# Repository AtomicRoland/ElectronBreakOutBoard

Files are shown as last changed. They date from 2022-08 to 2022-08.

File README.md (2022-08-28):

# ElectronBreakOutBoard
The break out / riser board for the Electron provides a way to check the Electron Plus1 cartridge slot signals during developing and error tracing of (new) boards.

You may choose to mount the 44 pin header strip on either side of the board. Just notice that if you mount it at the keyboard side, then pin 1 is not really pin 1 any more!

To mount the edge connector slot, first bend the pins on both rows slightly until there is a gap of about 1.6 mm. Then push it over the top edge connector (near the header) and solder the pins on both sides. That’s all.

*Please unzip the file myelin-kicad.pretty-master.zip before opening the project in KiCad.*

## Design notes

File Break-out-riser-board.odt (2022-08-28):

# Break out / Riser board for Acorn Electron

The break out / riser board for the Electron provides a way to check the Electron Plus1 cartridge slot signals during developing and error tracing of (new) boards. This board is small and easy to build because it only takes two passive components.

You may choose to mount the 44 pin header strip on either side of the board. Just notice that if you mount it at the keyboard side, then pin 1 is not really pin 1 any more!

To mount the edge connector slot, first bend the pins on both rows slightly until there is a gap of about 1.6 mm. Then push it over the top edge connector (near the header) and solder the pins on both sides. That’s all.

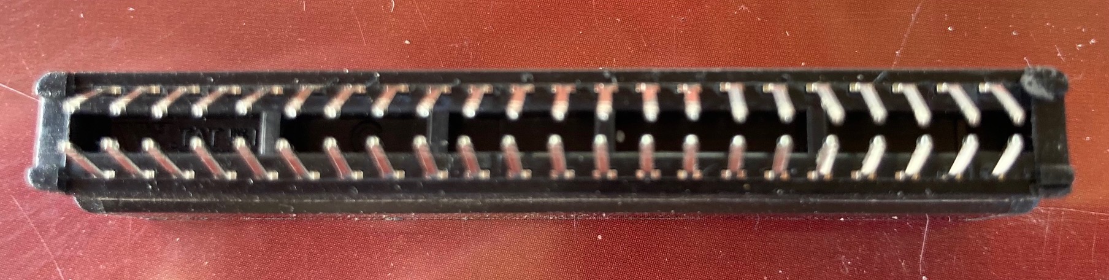
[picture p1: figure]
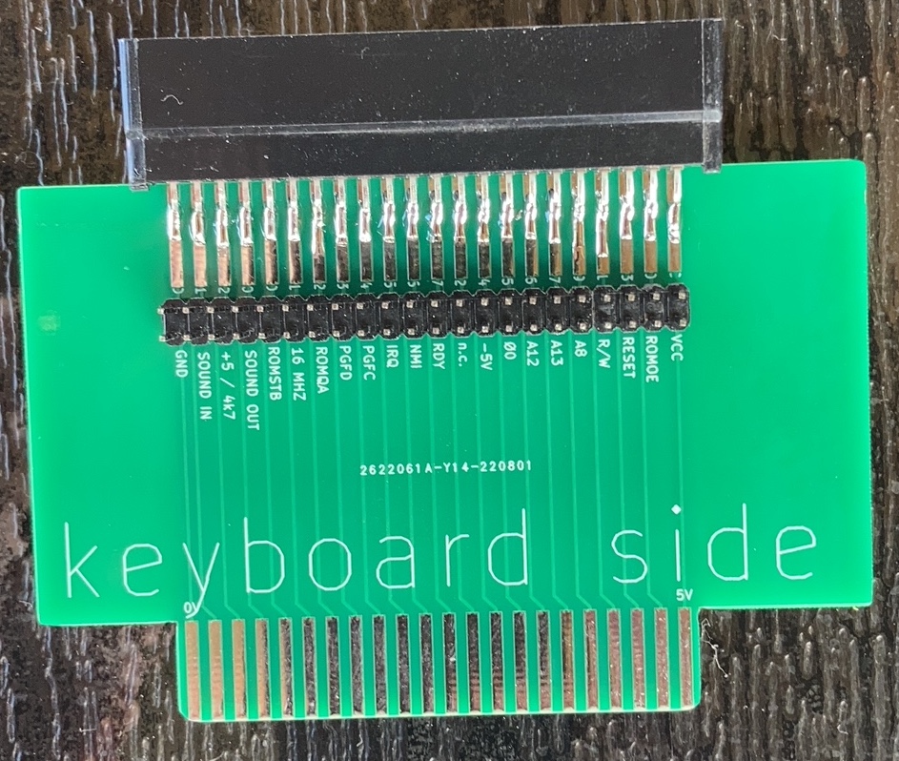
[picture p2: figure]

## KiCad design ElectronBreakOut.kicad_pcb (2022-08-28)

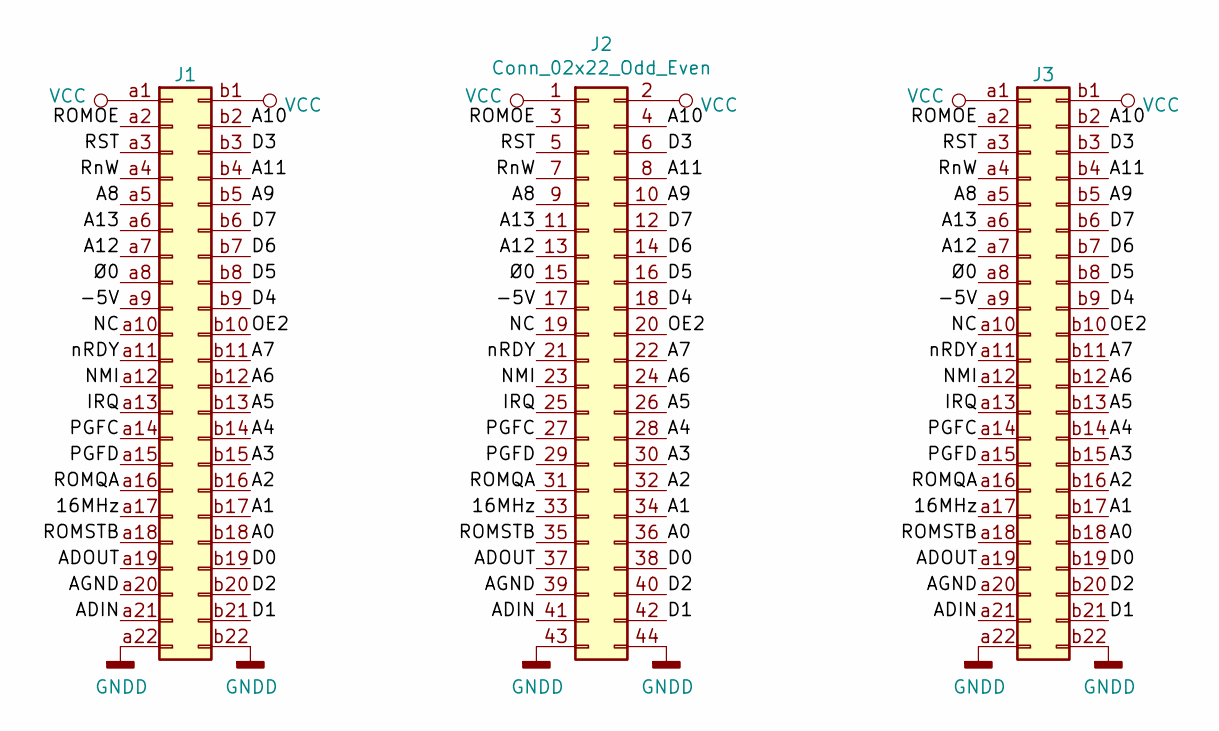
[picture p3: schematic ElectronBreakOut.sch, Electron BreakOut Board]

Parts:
J1: Conn_02x22_Row_Letter_First; acorn_electron_cartridge_edge_connector
J2: Conn_02x22_Odd_Even; PinHeader_2x22_P2.54mm_Vertical
J3: Conn_02x22_Row_Letter_First; acorn_electron_cartridge_edge_top

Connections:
/16MHz: J1.a17, J2.33, J3.a17
/-5V: J1.a9, J2.17, J3.a9
/A0: J1.b18, J2.36, J3.b18
/A1: J1.b17, J2.34, J3.b17
/A2: J1.b16, J2.32, J3.b16
/A3: J1.b15, J2.30, J3.b15
/A4: J1.b14, J2.28, J3.b14
/A5: J1.b13, J2.26, J3.b13
/A6: J1.b12, J2.24, J3.b12
/A7: J1.b11, J2.22, J3.b11
/A8: J1.a5, J2.9, J3.a5
/A9: J1.b5, J2.10, J3.b5
/A10: J1.b2, J2.4, J3.b2
/A11: J1.b4, J2.8, J3.b4
/A12: J1.a7, J2.13, J3.a7
/A13: J1.a6, J2.11, J3.a6
/ADIN: J1.a21, J2.41, J3.a21
/ADOUT: J1.a19, J2.37, J3.a19
/AGND: J1.a20, J2.39, J3.a20
/D0: J1.b19, J2.38, J3.b19
/D1: J1.b21, J2.42, J3.b21
/D2: J1.b20, J2.40, J3.b20
/D3: J1.b3, J2.6, J3.b3
/D4: J1.b9, J2.18, J3.b9
/D5: J1.b8, J2.16, J3.b8
/D6: J1.b7, J2.14, J3.b7
/D7: J1.b6, J2.12, J3.b6
/IRQ: J1.a13, J2.25, J3.a13
/NC: J1.a10, J2.19, J3.a10
/NMI: J1.a12, J2.23, J3.a12
/OE2: J1.b10, J2.20, J3.b10
/PGFC: J1.a14, J2.27, J3.a14
/PGFD: J1.a15, J2.29, J3.a15
/ROMOE: J1.a2, J2.3, J3.a2
/ROMQA: J1.a16, J2.31, J3.a16
/ROMSTB: J1.a18, J2.35, J3.a18
/RST: J1.a3, J2.5, J3.a3
/RnW: J1.a4, J2.7, J3.a4
/nRDY: J1.a11, J2.21, J3.a11
/Ø0: J1.a8, J2.15, J3.a8
GNDD: J1.a22, J1.b22, J2.43, J2.44, J3.a22, J3.b22
VCC: J1.a1, J1.b1, J2.1, J2.2, J3.a1, J3.b1

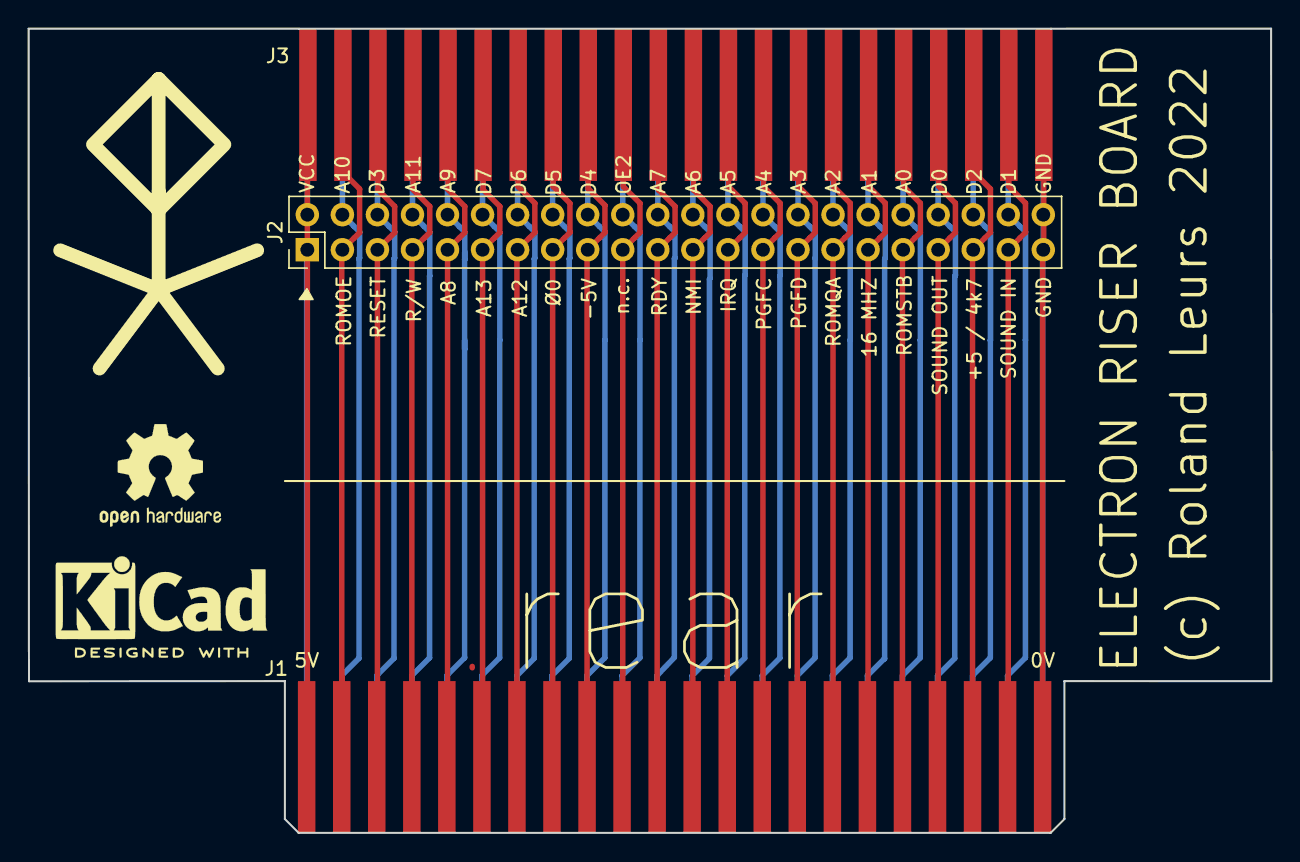
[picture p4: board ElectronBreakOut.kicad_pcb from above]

Board: 2 copper layers, 90.1 x 58.3 mm, 3 parts (0 on the bottom side), 42 nets.
